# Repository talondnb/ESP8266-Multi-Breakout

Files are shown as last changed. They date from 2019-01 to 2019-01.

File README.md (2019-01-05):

# ESP8266-Multi-Breakout

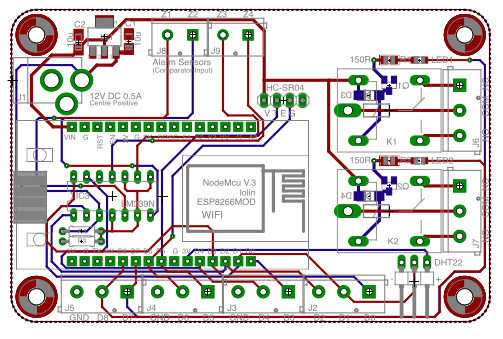
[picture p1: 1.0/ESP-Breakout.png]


This is an ESP8266 [NodeMCU V3 LoLin](https://www.aliexpress.com/item/ESP8266-CH340G-CH340-G-NodeMcu-V3-Lua-Wireless-WIFI-Module-Connector-Development-Board-Based-ESP-12E/32800966224.html) break-out PCB I've created for use with Home Assistant. I created this layout to allow for various functions; a garage door opener or retrofitting to a 'dumb' alarm system to integrate existing PIRs into your smart home setup.

The board will accept a +12VDC, 1A input via a 2.1MM centre positive jack. This voltage is regulated down to +5VDC via the onboard [AMS1117-5.0 linear regulator](http://www.advanced-monolithic.com/pdf/ds1117.pdf) to feed power to the two +5V relays and the NodeMCU V3.

The board also accommodates the following sensors:

[**DHT22**](https://www.aliexpress.com/item/DHT22-single-bus-digital-temperature-and-humidity-sensor-module-2302-electronic-building-blocks/32753887461.html) - Temperature and Humidity sensor

[**HC-SR04**](https://www.aliexpress.com/item/1pcs-HC-SR04-to-world-Ultrasonic-Wave-Detector-Ranging-Module-for-arduino-Distance-Sensor/32786781050.html) - Ultrasonic distance sensor

Aside from the above, a [LM339N](http://www.ti.com/lit/ds/symlink/lm339.pdf) is also available onboard and powered by the +12VDC input. This can be used to integrate your existing alarm system, to make use of the PIRs as binary sensors for motion detection without affecting the functionality of the original system. See [here](https://www.instructables.com/id/Alarm-PIR-Movement-to-Home-Automation/) for more information.

Pin out as follows:

| Pin  | Function | Comment
| --- | --- | --- |
| D0  | N/A  | Not used |
| D1  | Z1 or DHT22 input  | Only single input allowed |
| D2  | Z2 or other input  | Input/output |
| D3  | Z3 or other input  | Input/output |
| D4  | Z4 or other input  | Input/output |
| D5  | HC-SR04 (Trig)  | Ultrasonic distance sensor (if used) |
| D6  | HC-SR04 (Echo)  | Ultrasonic distance sensor (if used) |
| D7  | Relay #1  | Relay #1 trigger |
| D8  | Relay #2  | Relay #2 trigger |

See here for [pin reference](https://github.com/thehookup/Wireless_MQTT_Doorbell/blob/master/GPIO_Limitations_ESP8266_NodeMCU.jpg). 

Integration to Home Assistant can be done using the [esphomeyaml library](https://esphomelib.com/esphomeyaml/index.html).

This design was created using Eagle 7.3.

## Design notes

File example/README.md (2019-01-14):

***Alarm Panel***

This example uses the LM339 comparator to read the voltages of alarm sensors/PIR connected to an existing alarm panel and convert them to binary to be detectable by a smart home instance as a binary sensor. Refer to [here](https://www.instructables.com/id/Alarm-PIR-Movement-to-Home-Automation/).

I have also used both relay outputs on the board, wired into a wireless keyfob which can arm/disarm the alarm panel through existing RF integration.

***Garage Opener***

This example is uses a single relay output, wired directly to a garage door opener to trigger open/close. A cheap, wired [reed switch](https://www.aliexpress.com/item/Hot-Sale-1-Set-High-Sensitive-White-0-5A-100V-10W-ABS-1-Set-Door-Window/32672580621.html) is wired to D4 and GND to enable state detection of the garage door. The HC-SR04 ultrasonic sensor is also utilised as vehicle presence detection and the device is mounted above the vehicle parking area.

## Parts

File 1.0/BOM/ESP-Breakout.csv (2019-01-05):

Qty | Value | Device | Package | Parts | Description | Link
2 | M7 | DIODE-DO214AC | DO214AC | D3, D4 | DIODE | https://www.aliexpress.com/item/Free-Shipping-One-Lot-100pcs-SMD-1N4007-Rectifier-Diode-1A-1000V-M7-Original/2040310774.html
2 | LEDCHIP-LED0805 | LEDCHIP-LED0805 | CHIP-LED0805 | LED1, LED2 | LED | https://www.aliexpress.com/item/0805-smd-led-bright-red-thioindigo-red-light-emitting-diode/1206476683.html
1 |  | LM1117 | SOT223 | IC1 | 5.0V Regulator | https://www.aliexpress.com/item/10pcs-AMS1117-5-0-AMS1117-5-AMS1117-1117-5-0-SOT223-800mA-LOW-DROPOUT-VOLTAGE-REGULATOR/32831461170.html
1 |  | LOLINV3 | LOLINV3 | IC2 |  | https://www.aliexpress.com/item/New-Wireless-module-NodeMcu-Lua-WIFI-Internet-of-Things-development-board-based-ESP8266-with-pcb-Antenna/32656775273.html
2 |  | M025MM | SCREWTERMINAL-5MM-2 | J8, J9 | Standard 2-pin 0.1 header. Use with" | https://www.taydaelectronics.com/dg301-screw-terminal-block-2-positions-5mm.html
6 |  | M03-SCREW-5MM | SCREWTERMINAL-5MM-3 | J2, J3, J4, J5, J6, J7 | Header 3 | https://www.taydaelectronics.com/dg301-screw-terminal-block-3-positions-5mm.html
1 |  | PINHD-1X3/90 | 1X03/90 | DHT22 | PIN HEADER | https://www.taydaelectronics.com/connectors-sockets/pin-headers/40-pin-2-54-mm-angle-single-row-pin-header.html
2 | 10u | CPOL-EUA/3216-18W | A/3216-18W | C1, C2 | POLARIZED CAPACITOR, European symbol | https://www.aliexpress.com/item/20pcs-A-3216-10uF-16V-106-106C-SMD-tantalum-capacitor/32800884275.html
2 | 150R | R-EU_R0805 | R0805 | R1, R2 | RESISTOR, European symbol | https://www.taydaelectronics.com/resistors/smd-chip-resistors/0805/50-x-smd-chip-resistors-150-ohm-1-8w-1-0805.html
2 | BC850SMD | BC850SMD | SOT23-BEC | Q1, Q2 | NPN Transistor | https://www.taydaelectronics.com/ktc8050-transistor-npn-30v-0-8a-sot-23-3-ktc8050s-d-rtk.html
1 | POWER_JACKPTH | POWER_JACKPTH | POWER_JACK_PTH | J1 | Power Jack | https://www.taydaelectronics.com/dc-power-jack-2-1mm-barrel-type-pcb-mount.html
1 | V T E G | PINHD-1X4 | 1X04 | HC-SR04 | PIN HEADER | https://www.taydaelectronics.com/40-pin-2-54-mm-single-row-pin-header-strip.html
2 | ZF112 | ZF112 | ZF112 | K1, K2 | RELAY | https://www.taydaelectronics.com/mini-relay-spdt-5-pins-5vdc-10a-120v-contact.html
1 |  | Case | Case | Case | Plastic Project Case | https://www.taydaelectronics.com/hardware/enclosures/plastic-project-boxes/project-plastic-box-03.html
4 | M3x10 SCREW | M3x10 SCREW | M3x10 SCREW | M3x10 SCREW | M3x10 Plastic Screws
1 |  | HC-SR04 | HC-SR04 | HC-SR04 | (Optional) Proximity Sensor | https://www.aliexpress.com/item/1pcs-HC-SR04-to-world-Ultrasonic-Wave-Detector-Ranging-Module-for-arduino-Distance-Sensor/32786781050.html
1 |  | DHT22 | DHT22 | DHT22 | (Optional) Temperature/Humidity Sensor | https://www.aliexpress.com/item/DHT22-single-bus-digital-temperature-and-humidity-sensor-module-2302-electronic-building-blocks/32753887461.html
1 | LM339N | LM339N | DIL14 | IC3 | (Optional) Low Power Low Offset Voltage Quad Comparators | https://www.taydaelectronics.com/lm339n-lm339-low-power-quad-voltage-comparators-ic.html
2 |  | R-EU_0204/7 | 0204/7 | R3, R4 | (Optional) Voltage Divider (www.ohmslawcalculator.com/voltage-divider-calculator) | https://www.instructables.com/id/Alarm-PIR-Movement-to-Home-Automation/

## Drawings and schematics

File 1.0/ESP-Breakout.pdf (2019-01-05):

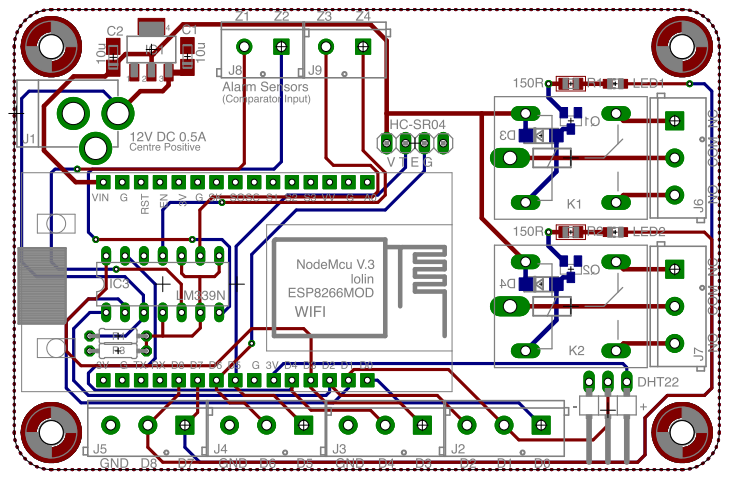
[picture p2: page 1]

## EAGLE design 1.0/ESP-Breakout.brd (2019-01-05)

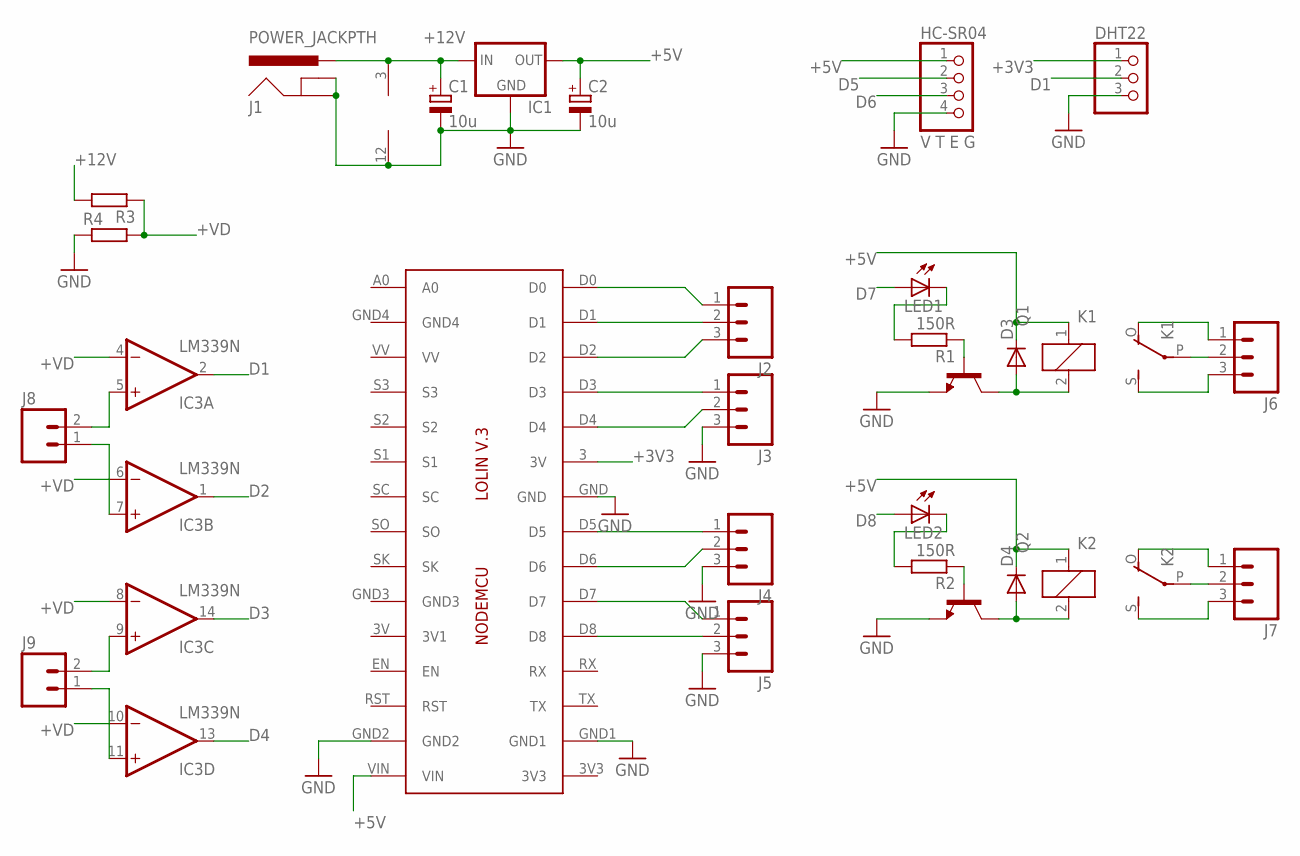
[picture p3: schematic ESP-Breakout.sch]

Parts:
C1, C2: 10u; A/3216-18W
D3, D4: DIODE-DO214AC; DO214AC
DHT22: PINHD-1X3/90; 1X03/90
HC-SR04: V T E G; 1X04
IC1: LM1117; SOT223
IC2: LOLINV3
IC3: LM339N; DIL14
J1: POWER_JACKPTH; POWER_JACK_PTH
J2, J3, J4, J5, J6, J7: M03-SCREW-5MM; SCREWTERMINAL-5MM-3
J8, J9: M025MM; SCREWTERMINAL-5MM-2
K1, K2: ZF112
LED1, LED2: LEDCHIP-LED0805; CHIP-LED0805
Q1, Q2: BC850SMD; SOT23-BEC
R1, R2: 150R; R0805
R3, R4: R-EU_0204/7; 0204/7

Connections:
+3V3: DHT22.1, IC2.3 (3V)
+5V: C2.+, D3.C, D4.C, HC-SR04.1, IC1.2 (OUT), IC2.VIN, K1.1, K2.1
+12V: C1.+, IC1.3 (IN), IC3.3 (V+), J1.PWR, R3.2
+VD: IC3.4 (-IN), IC3.6 (-IN), IC3.8 (-IN), IC3.10 (-IN), R3.1, R4.2
D0: IC2.D0, J2.1
D1: DHT22.2, IC2.D1, IC3.2 (OUT), J2.2
D2: IC2.D2, IC3.1 (OUT), J2.3
D3: IC2.D3, IC3.14 (OUT), J3.1
D4: IC2.D4, IC3.13 (OUT), J3.2
D5: HC-SR04.2, IC2.D5, J4.1
D6: HC-SR04.3, IC2.D6, J4.2
D7: IC2.D7, J5.1, LED1.A
D8: IC2.D8, J5.2, LED2.A
GND: C1.-, C2.-, DHT22.3, HC-SR04.4, IC1.1 (GND), IC2.GND, IC2.GND1, IC2.GND2, IC3.12 (GND), J1.GND, J1.GNDBREAK, J3.3, J4.3, J5.3, Q1.E, Q2.E, R4.1
unnamed: IC3.5 (+IN), J8.2
unnamed: IC3.7 (+IN), J8.1
unnamed: IC3.9 (+IN), J9.2
unnamed: IC3.11 (+IN), J9.1
unnamed: J6.2, K1.P
unnamed: J6.3, K1.S
unnamed: J6.1, K1.O
unnamed: J7.2, K2.P
unnamed: J7.1, K2.O
unnamed: J7.3, K2.S
unnamed: D3.A, K1.2, Q1.C
unnamed: D4.A, K2.2, Q2.C
unnamed: Q1.B, R1.1
unnamed: Q2.B, R2.1
unnamed: LED1.C, R1.2
unnamed: LED2.C, R2.2

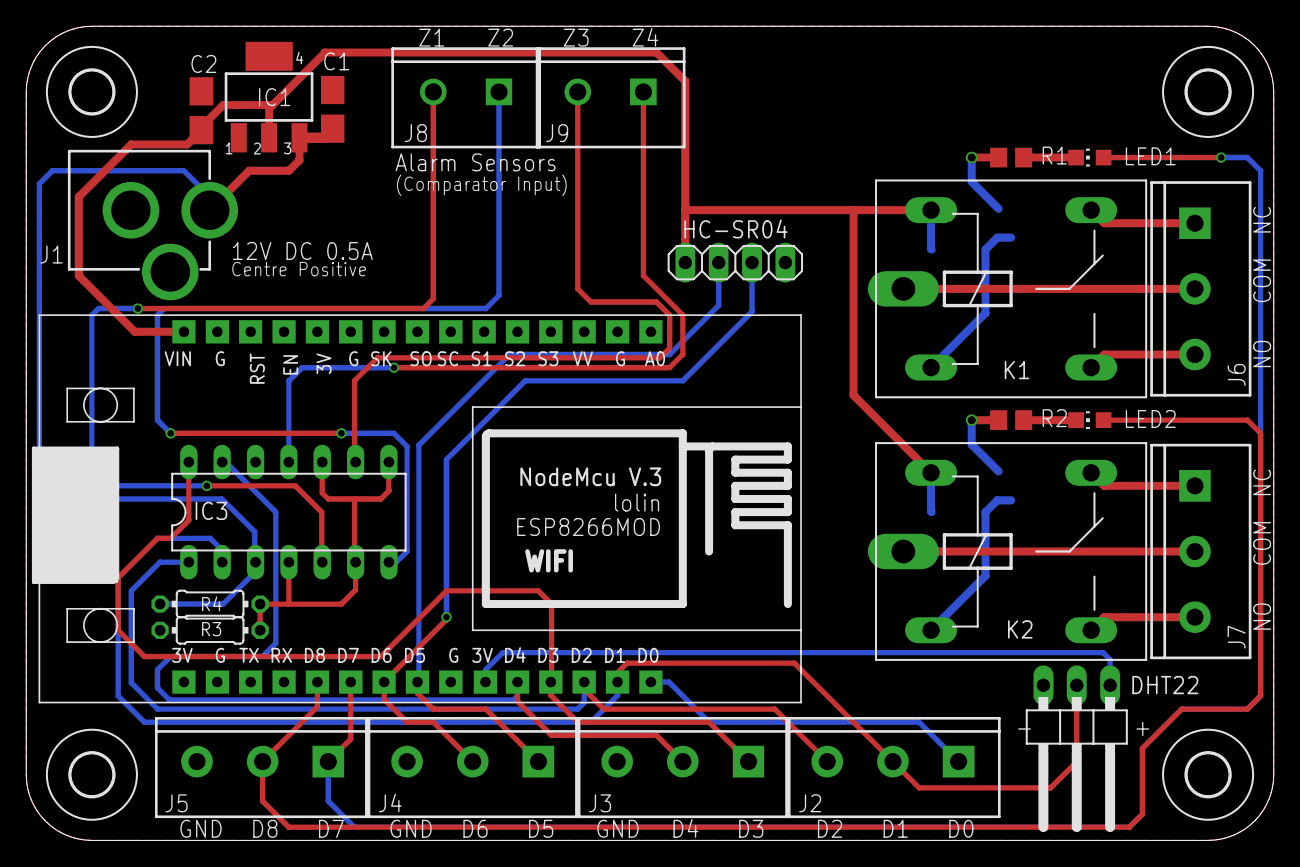
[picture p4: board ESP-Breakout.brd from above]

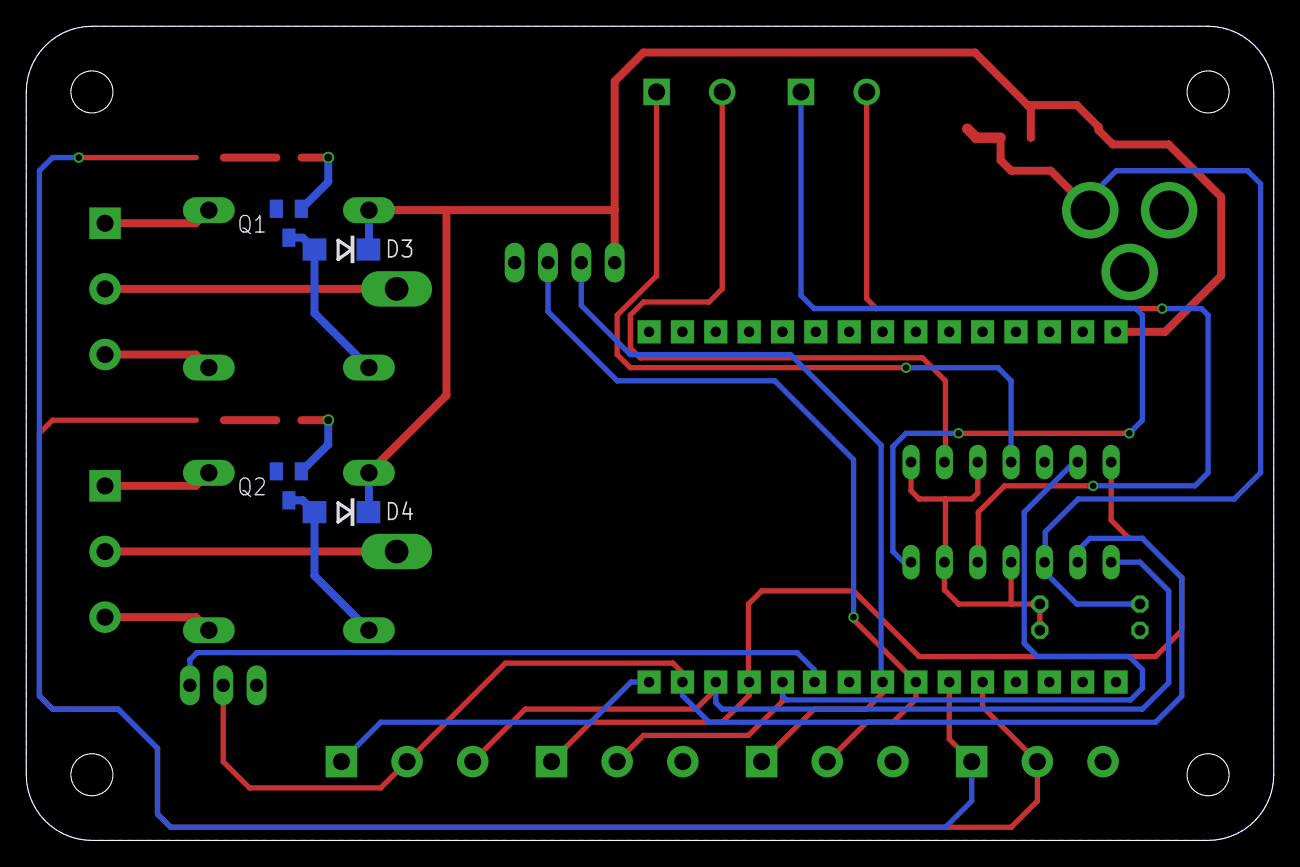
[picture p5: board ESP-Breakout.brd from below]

Board: 2 copper layers, 95.0 x 62.0 mm, 32 parts (4 on the bottom side), 30 nets.

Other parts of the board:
U$2, U$3, U$4, U$5: 3,2

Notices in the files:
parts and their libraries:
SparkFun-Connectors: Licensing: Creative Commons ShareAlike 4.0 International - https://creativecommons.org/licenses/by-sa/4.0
